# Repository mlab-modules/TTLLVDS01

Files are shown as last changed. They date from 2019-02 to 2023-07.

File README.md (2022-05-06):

<!--- PrjInfo ---> <!--- Please remove this line after manually editing --->
<!--- 00a56be08b96043df9e37d6aff7b6990 --->
<!--- Created:2019-02-18 14:57:49.031132: ---> 
<!--- Author:: ---> 
<!--- AuthorEmail:: ---> 
<!--- Tags:: ---> 
<!--- Ust:: ---> 
<!--- Label --->
<!--- ELabel ---> 
<!--- Name:TTLLVDS01A: --->
# TTLLVDS01A
<!--- LongName --->
## TTL to LVDS converter and vice versa
<!--- ELongName ---> 

<!--- Lead --->
TTLLVDS is TTL to LVDS and LVDS to TTL converter. Module can be used to connect a simple TTL signal to LVDS input. By changing the components, it can acts as LVDS to TTL convertor. To covert differencial LVDS signal to TTL output. Each module converts two signals. 
<!--- ELead ---> 

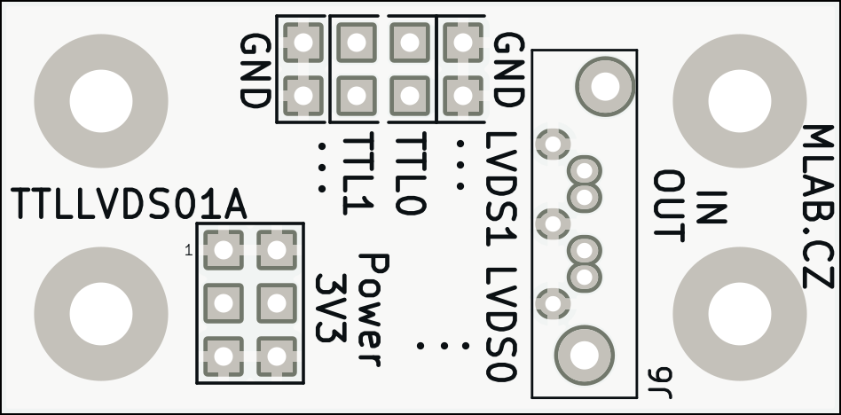
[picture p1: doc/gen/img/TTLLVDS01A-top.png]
TTLLVDS01A
 

<!--- Description --->
The TTL signal is connected using a simple header. Differential LVDS signal is connected trought SATA connector and cable. Each sata connector contains two pairs of LVDS signals.

Module require a 3v3 powering. 
<!--- EDescription --->
<!--- Content --->
<!--- EContent --->

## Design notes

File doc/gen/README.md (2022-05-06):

# PCB

Board size: 40.13x19.81 mm (1.58x0.78 inches)

- This is the size of the rectangle that contains the board
- Thickness: 1.6 mm (63 mils)
- Material: FR4
- Finish: None
- Layers: 2
- Copper thickness: 35 µm

Solder mask: TOP / BOTTOM

- Color: Green

Silk screen: TOP / BOTTOM

- Color: White

Stackup:

| Name | Type | Color | Thickness | Material | Epsilon_r | Loss tangent |
|---|---|---|---|---|---|---|
| F.SilkS | Top Silk Screen | | | | | |
| F.Mask | Top Solder Mask | | 10 | | | |
| F.Cu | copper | | 35 | | | |
| dielectric 1 | core | | 1510 | FR4 | 4.5 | 0.02 |
| B.Cu | copper | | 35 | | | |
| B.Mask | Bottom Solder Mask | | 10 | | | |
| B.Paste | Bottom Solder Paste  | | | | | |
| B.SilkS | Bottom Silk Screen | | | | | |

# Important sizes

Clearance: 0.2 mm (8 mils)

Track width: 0.3 mm (12 mils)

- By design rules: 0.2 mm (8 mils)

Drill: 0.4 mm (16 mils)

- Vias: 0.4 mm (16 mils) [Design: 0.3 mm (12 mils)]
- Pads: 0.74 mm (29 mils)

Via: 0.8/0.4 mm (31/16 mils)

- By design rules: 0.4/0.3 mm (16/12 mils)
- Micro via: no [0.2/0.1 mm (8/4 mils)]
- Burried/blind via: no

Outer Annular Ring: 0.36 mm (14 mils)

- By design rules: 0.36 mm (14 mils)

Eurocircuits class: 4C

# General stats

Components count: (SMD/THT)

- Top: 0/10 (THT)
- Bottom: 7/0 (SMD)

Defined tracks:

- 0.3 mm (12 mils)
- 0.5 mm (20 mils)
- 0.8 mm (31 mils)
- 1.0 mm (39 mils)

Used tracks:

- 0.3 mm (12 mils) (2) defined: yes
- 0.4 mm (16 mils) (38) defined: no
- 0.5 mm (20 mils) (16) defined: yes
- 1.0 mm (39 mils) (6) defined: yes

Defined vias:

Used vias:

- 0.8/0.4 mm (31/16 mils) (Count: 9, Aspect: 2.0 A) defined: no

Holes (excluding vias):

- 0.74 mm (29 mils) (7)
- 0.89 mm (35 mils) (14)
- 1.35 mm (53 mils) (2)
- 3.0 mm (118 mils) (4)

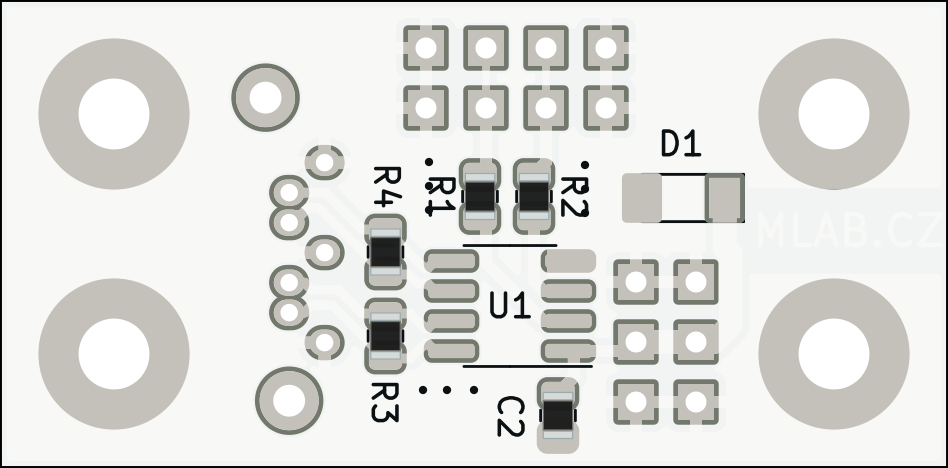
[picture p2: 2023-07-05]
doc/gen/img/TTLLVDS01-bottom.png

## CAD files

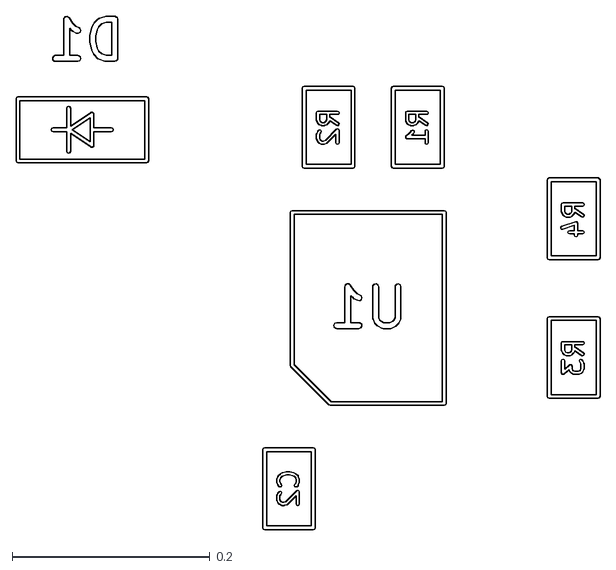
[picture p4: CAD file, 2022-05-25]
doc/gen/dxf/TTLLVDS01-B_Fab.dxf
0.59 x 0.518

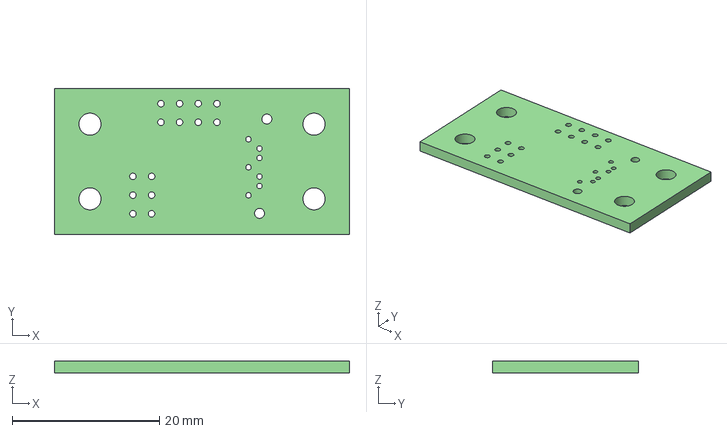
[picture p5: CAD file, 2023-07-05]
doc/gen/TTLLVDS01.step
40.1 x 19.8 x 1.60 mm

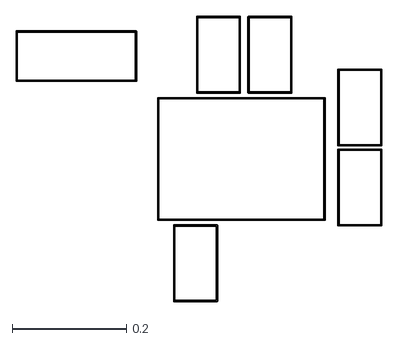
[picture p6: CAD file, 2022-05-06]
doc/gen/dxf/TTLLVDS01-B_Courtyard.dxf
0.64 x 0.499

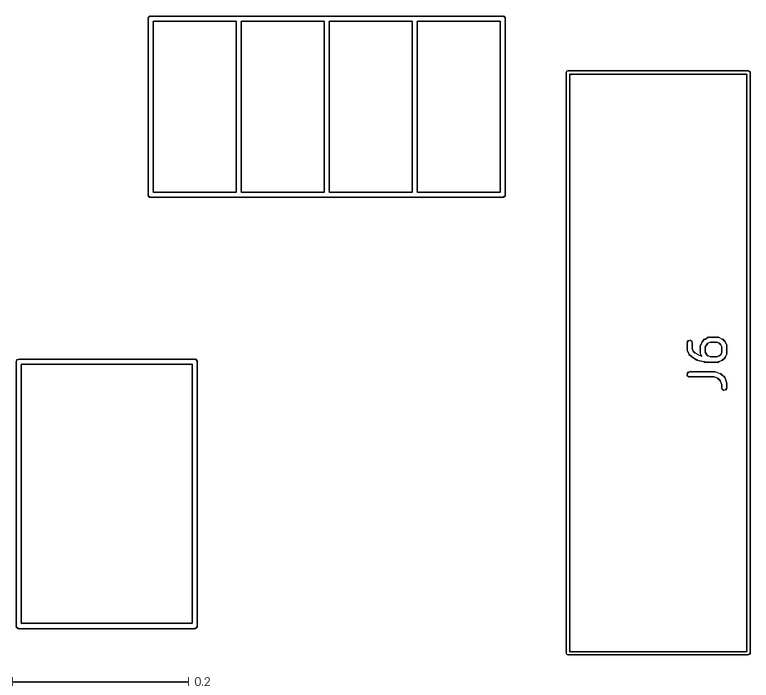
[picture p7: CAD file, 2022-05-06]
doc/gen/dxf/TTLLVDS01-F_Fab.dxf
0.834 x 0.726

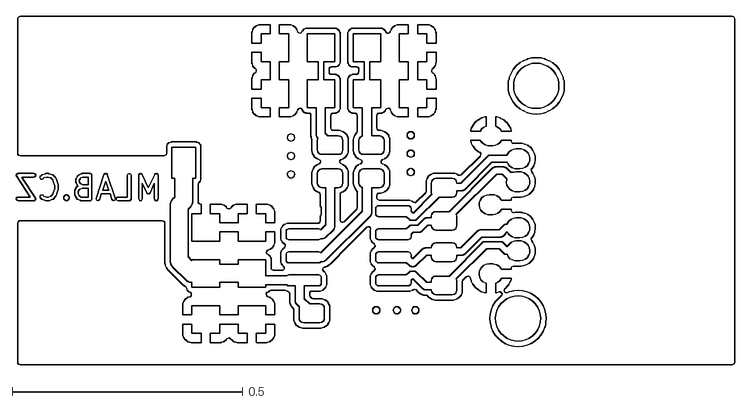
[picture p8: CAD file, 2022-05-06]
doc/gen/dxf/TTLLVDS01-B_Cu.dxf
1.56 x 0.756

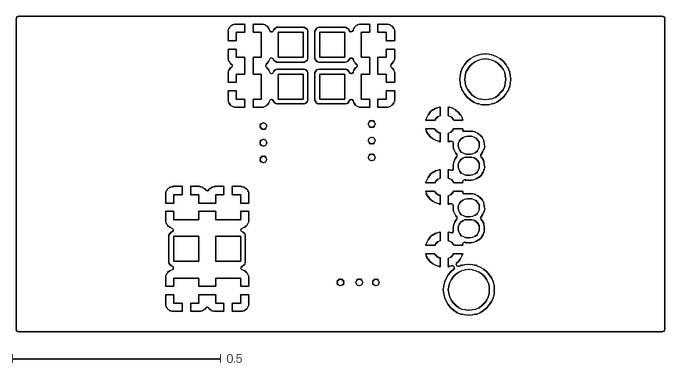
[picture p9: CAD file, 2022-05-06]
doc/gen/dxf/TTLLVDS01-F_Cu.dxf
1.56 x 0.756

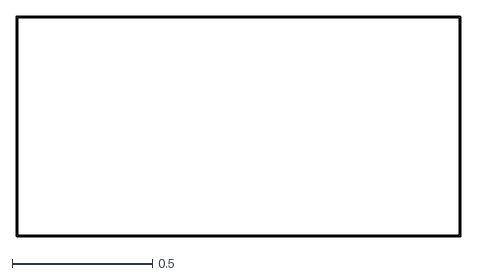
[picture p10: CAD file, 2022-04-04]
doc/gen/dxf/TTLLVDS01-Edge_Cuts.dxf
1.59 x 0.786

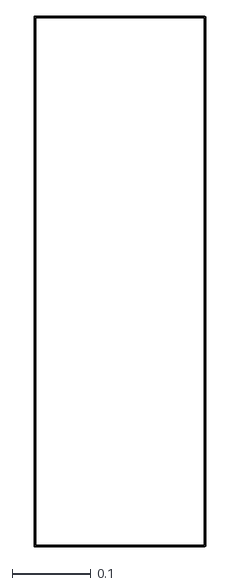
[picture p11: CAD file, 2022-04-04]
doc/gen/dxf/TTLLVDS01-F_Courtyard.dxf
0.219 x 0.675

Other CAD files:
doc/gen/TTLLVDS01A.step
doc/gen/dxf/TTLLVDS01-Margin.dxf
doc/gen/dxf/TTLLVDS01-B_Mask.dxf
doc/gen/dxf/TTLLVDS01-B_Paste.dxf
doc/gen/dxf/TTLLVDS01-B_Silkscreen.dxf
doc/gen/dxf/TTLLVDS01-F_Mask.dxf
doc/gen/dxf/TTLLVDS01-F_Silkscreen.dxf

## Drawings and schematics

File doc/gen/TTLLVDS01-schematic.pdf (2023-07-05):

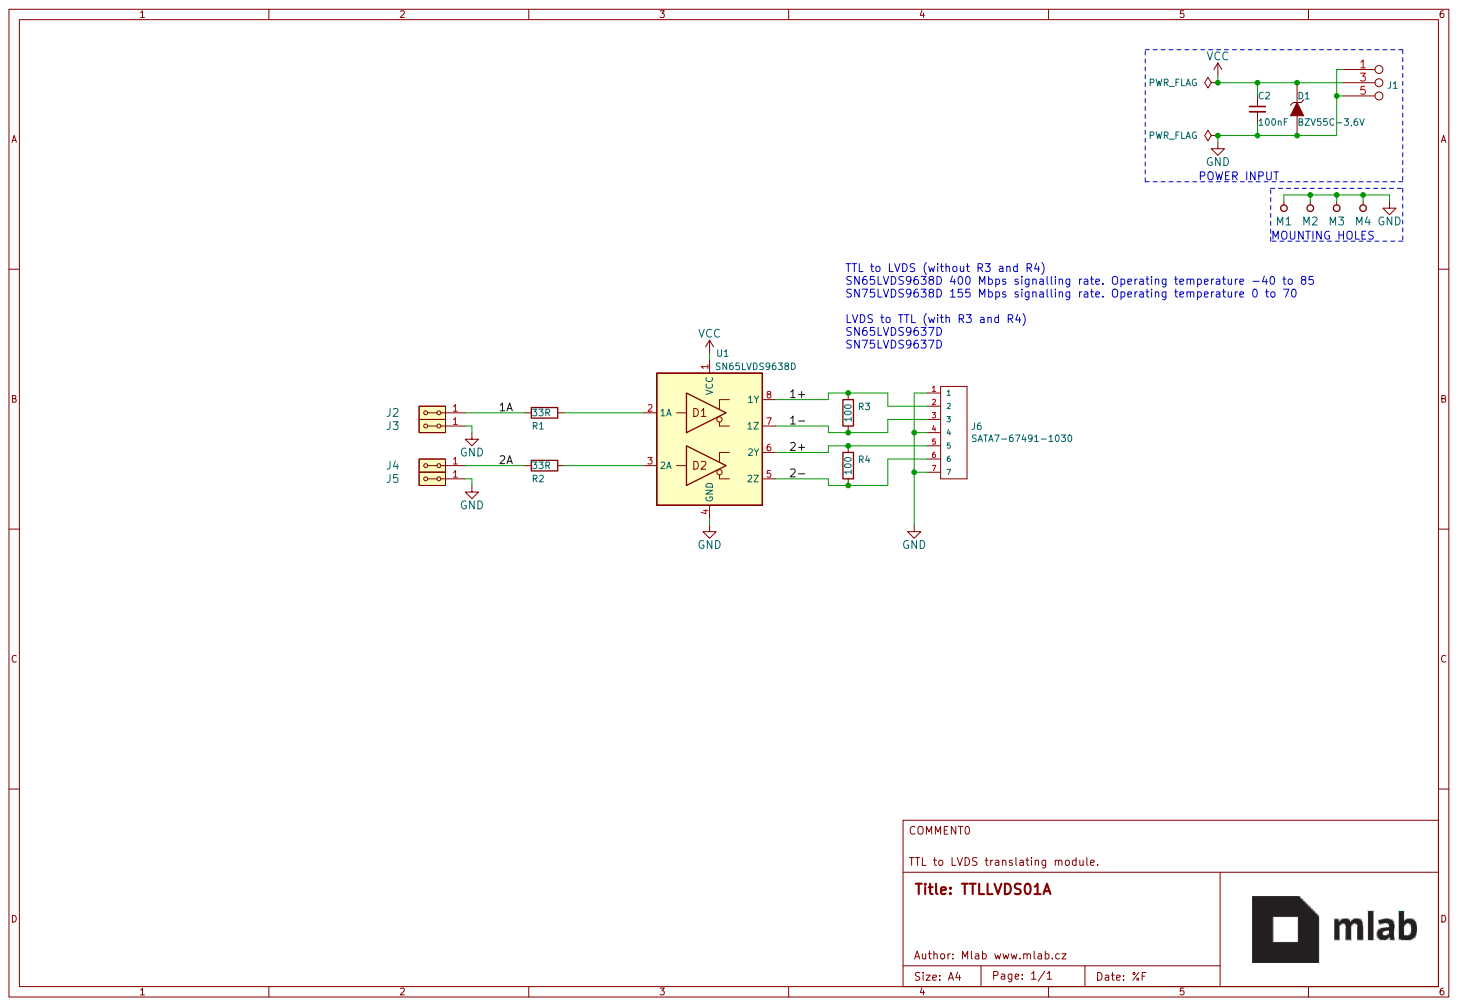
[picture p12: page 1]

TTL to LVDS (without R3 and R4)
SN65LVDS9638D 400 Mbps signalling rate. Operating temperature -40 to 85
SN75LVDS9638D 155 Mbps signalling rate. Operating temperature 0 to 70

COMMENT0 TTL to LVDS translating module.

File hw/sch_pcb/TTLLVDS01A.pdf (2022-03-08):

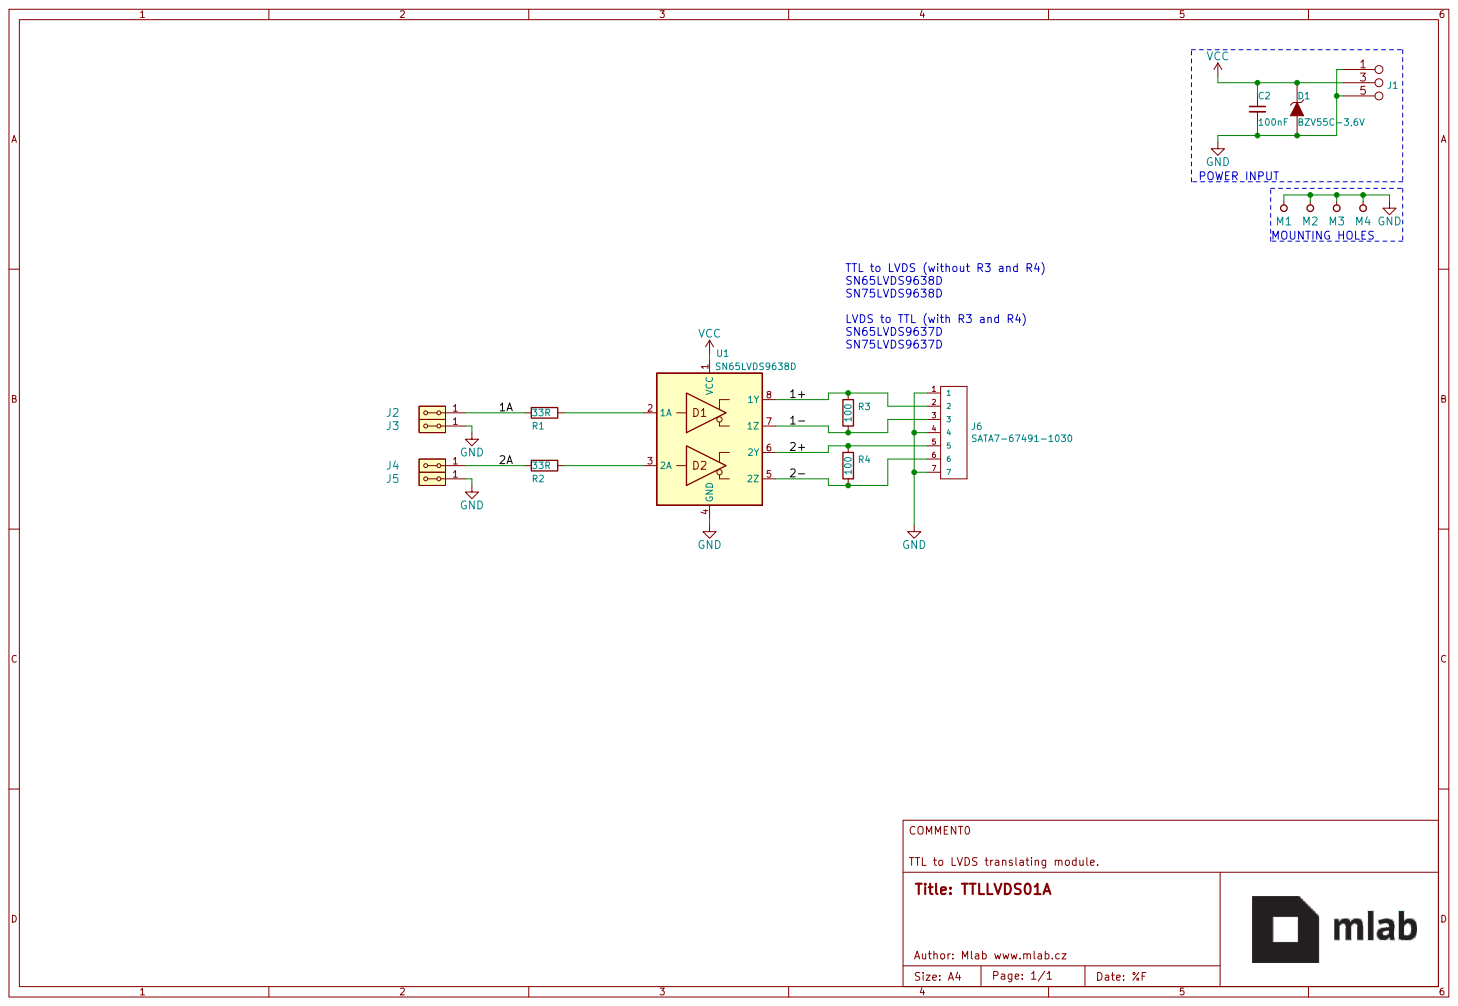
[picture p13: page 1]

COMMENT0 TTL to LVDS translating module.

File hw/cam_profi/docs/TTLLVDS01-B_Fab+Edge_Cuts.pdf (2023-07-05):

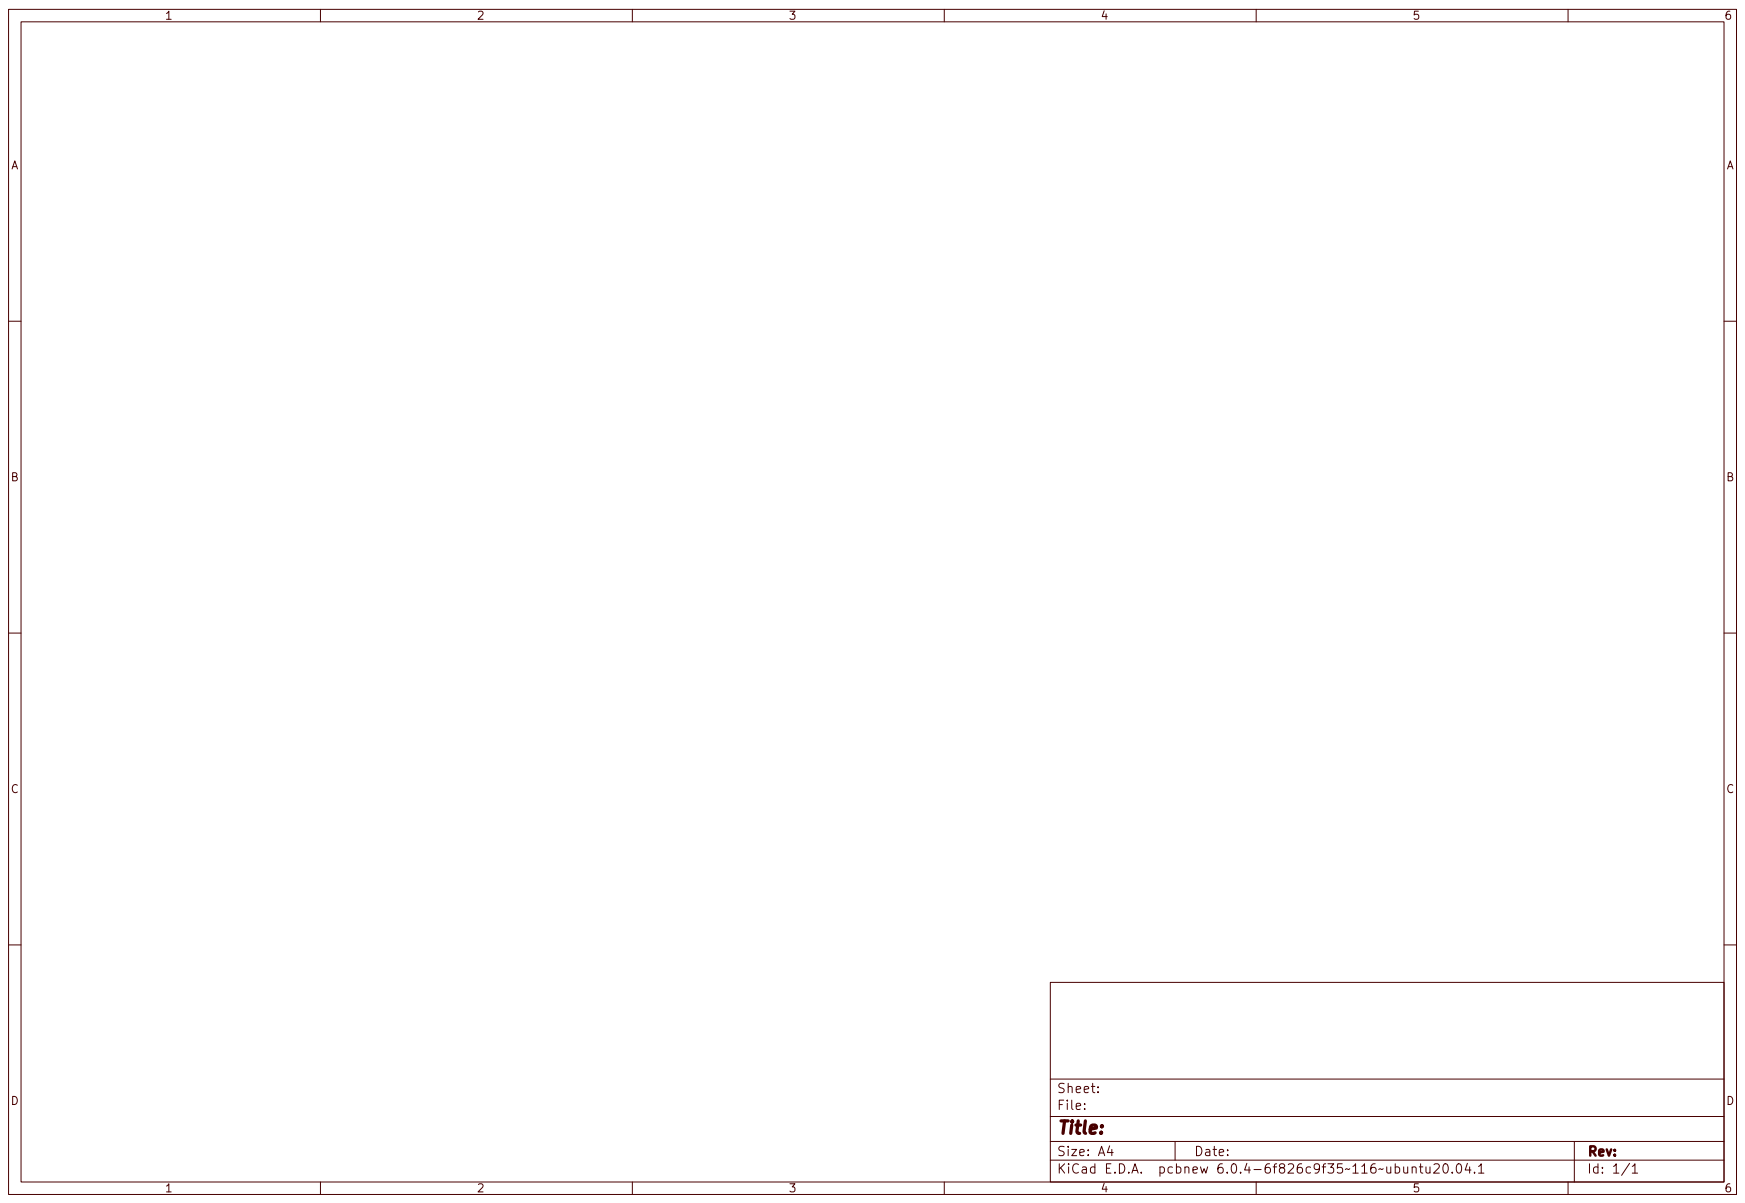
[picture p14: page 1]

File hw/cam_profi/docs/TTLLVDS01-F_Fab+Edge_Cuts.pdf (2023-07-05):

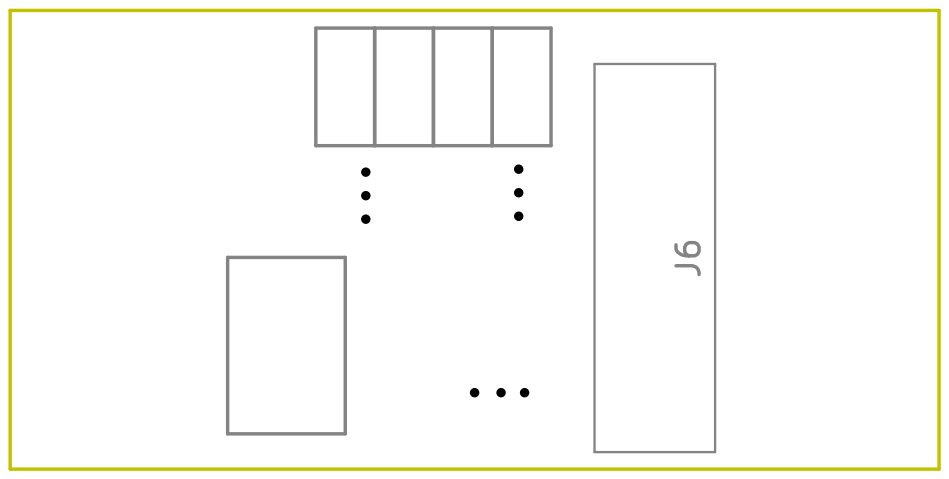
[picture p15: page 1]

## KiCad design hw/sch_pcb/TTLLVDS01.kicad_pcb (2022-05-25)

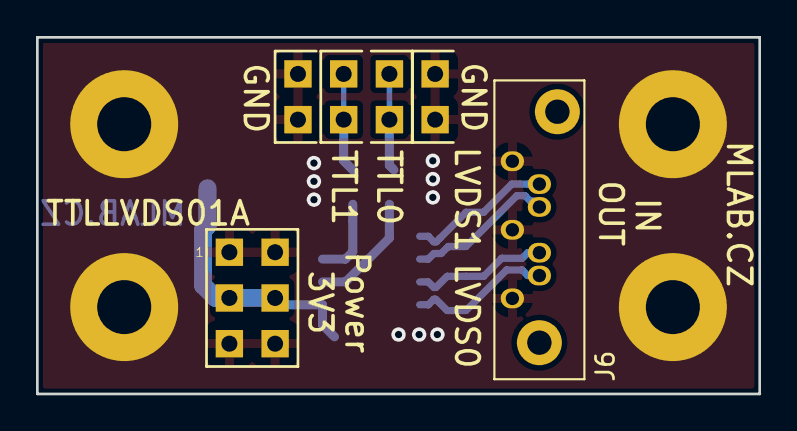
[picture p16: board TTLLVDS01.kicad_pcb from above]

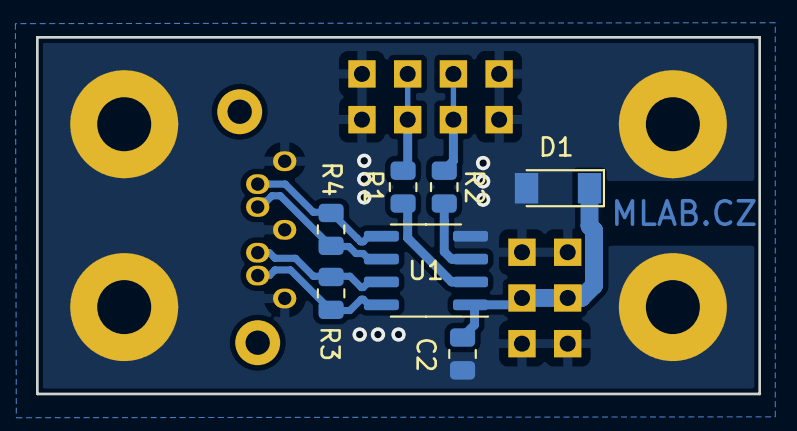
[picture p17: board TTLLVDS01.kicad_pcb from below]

Board: 2 copper layers, 40.1 x 19.8 mm, 17 parts (7 on the bottom side), 10 nets.

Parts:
C2: 100nF; R_0805_2012Metric
D1: BZV55C-3,6V; D_MiniMELF
J1: JUMP_3X2; Straight_2x03
J2, J3, J4, J5: HEADER_2x01_PARALLEL; Straight_2x01
J6: SATA7-67491-1030; SATA-7_THT_VERT_2
M1, M2, M3, M4: HOLE; MountingHole_3mm
R1, R2: 33R; R_0805_2012Metric
R3, R4: 100; R_0805_2012Metric
U1: SN65LVDS9638D; SOIC-8_3.9x4.9mm_P1.27mm

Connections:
/1+: J6.2, R3.1, U1.8 (1Y)
/1-: J6.3, R3.2, U1.7 (1Z)
/1A: J2.1, J2.2, R1.2
/2+: J6.5, R4.1, U1.6 (2Y)
/2-: J6.6, R4.2, U1.5 (2Z)
/2A: J4.1, J4.2, R2.2
GND: C2.2, D1.2 (A), J1.1 (2), J1.2, J1.5 (6), J1.6, J3.1, J3.2, J5.1, J5.2, J6.1, J6.4, J6.7, M1.1, M2.1, M3.1, M4.1, U1.4 (GND)
unnamed: R1.1, U1.2 (1A)
unnamed: R2.1, U1.3 (2A)
VCC: C2.1, D1.1 (K), J1.3 (4), J1.4, U1.1 (VCC)

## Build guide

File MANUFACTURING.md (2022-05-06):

Po osazení modulu standartním způsobem je potřeba v silk-screenu označit, kterým směrem je převodník konfigurován.

IN (škrtnout OUT) znamená LVDS -> TTL
OUT (škrtout IN) znamená TTL -> LVDS

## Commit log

2019-02-18 [MLABweb] Documentaion edits; TTLLVDS01A
    [TTLLVDS01A.kicad_pcb, TTLLVDS01A.sch]
2019-02-19 Edit PCB
    [TTLLVDS01A.kicad_pcb, TTLLVDS01A.sch]
2019-04-08 Rendering printable file.
2022-03-08 Update project to KiCAD 6.0. Update PCB silkscreen.
    [TTLLVDS01A.kicad_pcb, TTLLVDS01A.kicad_sch, TTLLVDS01A.sch]
2022-04-04 Update documentation.
    [TTLLVDS01A.kicad_pcb, TTLLVDS01A.kicad_sch]
2022-04-04 Fix title block path issue. Fix submodule versions.
    [TTLLVDS01A.kicad_sch]
2022-04-04 Update actions products
    [TTLLVDS01A-B_Courtyard.dxf, TTLLVDS01A-B_Cu.dxf, TTLLVDS01A-B_Fab.dxf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]
2022-05-06 Zmena pouzder na nova KiCAD a poslední kontroly pred vyrobou
    [TTLLVDS01A-B_Cu.gbr, TTLLVDS01A-B_Mask.gbr, TTLLVDS01A-B_Paste.gbr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]
2022-05-25 Priprava podkladu pro vyrobu
    [TTLLVDS01A.kicad_pcb, TTLLVDS01A.kicad_sch]
2023-07-05 automated commit; rename source files to new naming convence
    [TTLLVDS01.kicad_pcb, TTLLVDS01.kicad_sch]
